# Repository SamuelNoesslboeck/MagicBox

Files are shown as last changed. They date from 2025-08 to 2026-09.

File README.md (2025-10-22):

# MagicBox

The MagicBox is a WiFi/BlueTooth- and LoRa-able, programmable radio controller for a large range of applications. 

## Hardware

<p align="center">
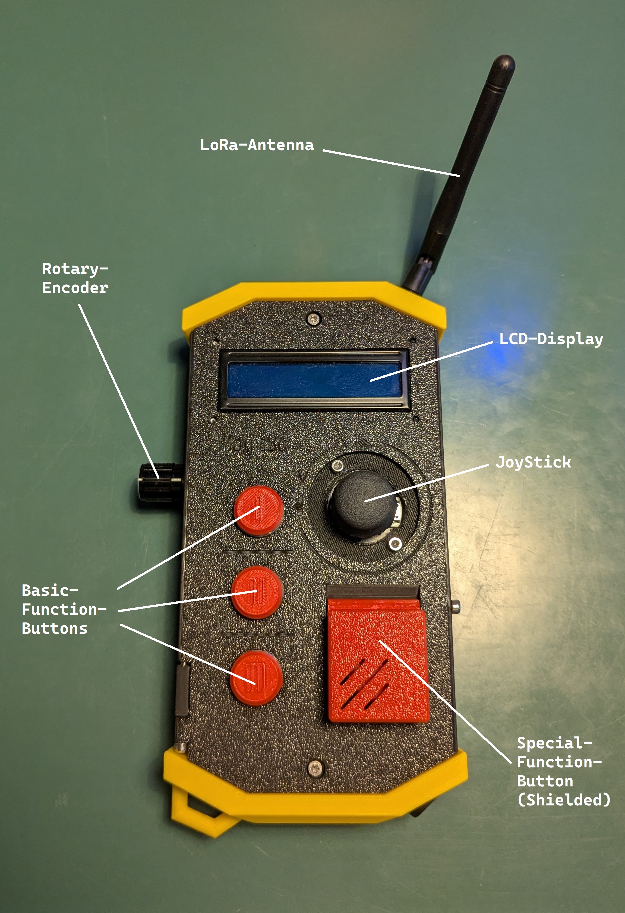
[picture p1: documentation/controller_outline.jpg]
    
</p>

Equipped with an ESP32 MCU, the controller can host quite challenging tasks and code. It's various input and output devices include:

- LCD Display
- Buzzer
- Rotary encoder
- Joystick
- 3 open and 1 shielded button

For more information, see the hardware reference [here](./documentation/hardware_reference.md).

## Software & Programming

The controller is fully programmable, meaning it can be adjusted to every application. Some basic APIs and libraries are provided:

- [magicontent](https://github.com/SamuelNoesslboeck/magicontent): Provides basic hardware bindings and APIs so you can start directly with tailoring the controller to your application
- [magicos](https://github.com/SamuelNoesslboeck/magicos): Some pre-made programs for general applications of the controller (LoRa-Mode, USB-Mode, ... )

The controller includes a simple OP-Code protocol called MBCP, which is generally transferred via LoRa. For more information, see [magicontent](https://github.com/SamuelNoesslboeck/magicontent).

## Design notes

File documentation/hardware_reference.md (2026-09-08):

# Hardware-Reference

The hardware reference gives an overview over the electrical components and connections used.

## Components used

- **MCU**: ESP32 (Type: NodeMCU32S)
- **LCD-Display**: LCD-2004 (Using a I2C adapter)
- **LoRa-Module**: 

## ESP32 - Pin reference 

| ID | Pin | Description |
|---|---|---|
| | | |
| **JoyStick** | | | 
| JS_X | 4 | Analog signal value for X direction of the Joystick (0-3.3V) |
| JS_Y | 34 | Analog signal value for Y direction of the Joystick (0-3.3V) |
| | | |
| **Buttons** | | |
| BT_A1 | 16 | First action button on the front |
| BT_A2 | 17 | Second action button on the front |
| BT_A3 | 25 | Third action button on the front |
| BT_ULT | 26 | Ultimate action button on the front |
| | | |
| **Rot-Encoder** | | |
| RE_DT | 39 | Data signal line of the rotary encoder |
| RE_CL | 36 | Clock signal line of the rotary encoder |
| RE_SW | 13 | Integrated rotary encoder button |
| | | |
| **LoRa** | | |
| LORA_SS | 5 | > |
| LORA_RST | 14 | > LoRa Data connection |
| LORA_D0 | 27 | > |
| | | |
| **Misc.** | | |
| BUZZER | 2 | PWM Pin to play notes on the buzzer |

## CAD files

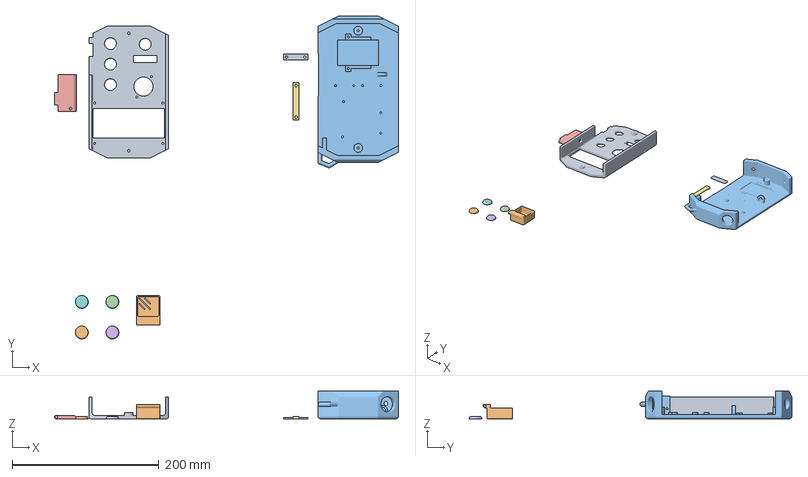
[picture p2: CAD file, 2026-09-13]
printing/a__magicbox.3mf
469.3 x 440.6 x 38.0 mm
1_top_plate.stl
3__button_cap.stl
2_outer_shell.stl
7a__button1.stl
4_left_opening.stl
7b__button2.stl
5_battery_clamp.stl
7c__button3.stl
6_module_clamp.stl
7d__buttonS.stl

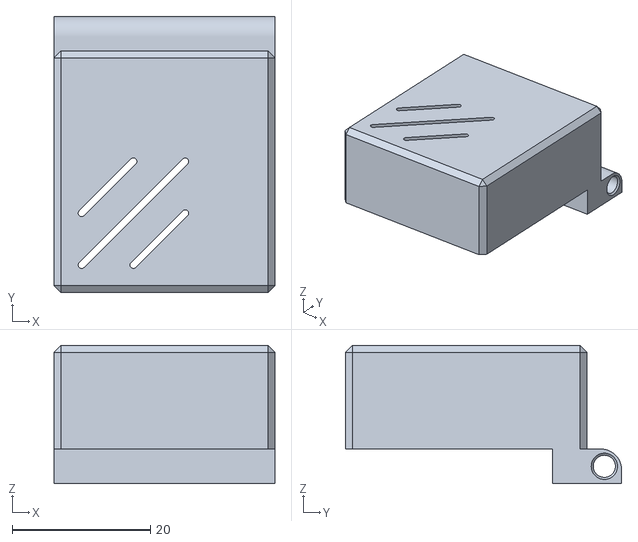
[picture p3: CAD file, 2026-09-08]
printing/3__button_cap.stl
32.0 x 40.0 x 20.0

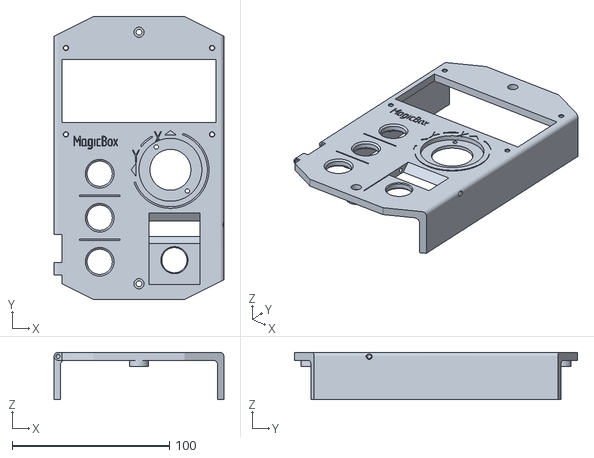
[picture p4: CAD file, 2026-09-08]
printing/1__top_plate.stl
108.0 x 180.0 x 30.0

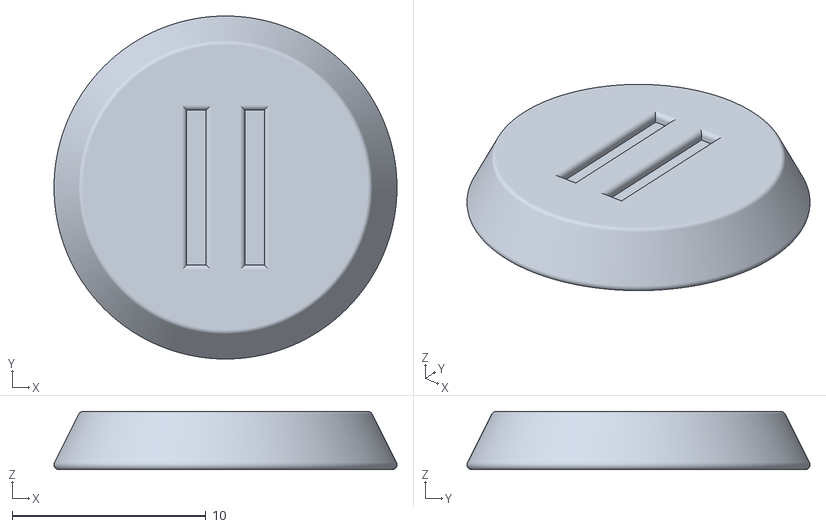
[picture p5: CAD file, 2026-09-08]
printing/7b__button2.stl
17.7 x 17.7 x 3.00

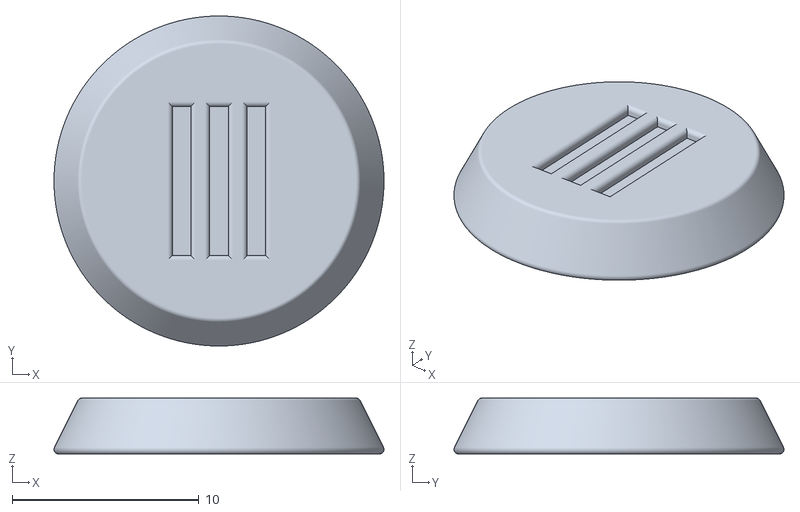
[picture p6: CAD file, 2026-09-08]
printing/7c__button3.stl
17.7 x 17.7 x 3.00

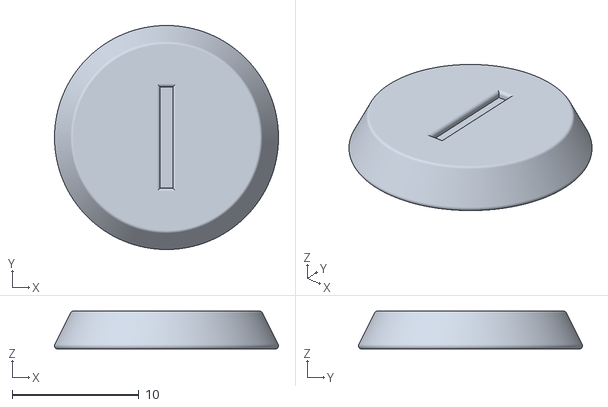
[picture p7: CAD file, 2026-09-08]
printing/7a__button1.stl
17.7 x 17.7 x 3.00

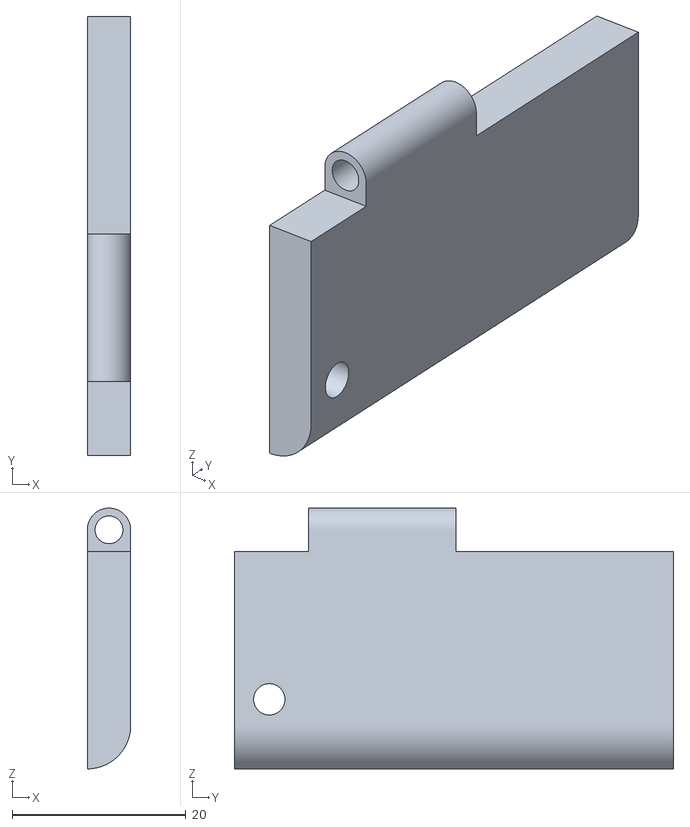
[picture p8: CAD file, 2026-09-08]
printing/4__left_opening.stl
5.00 x 50.5 x 30.0

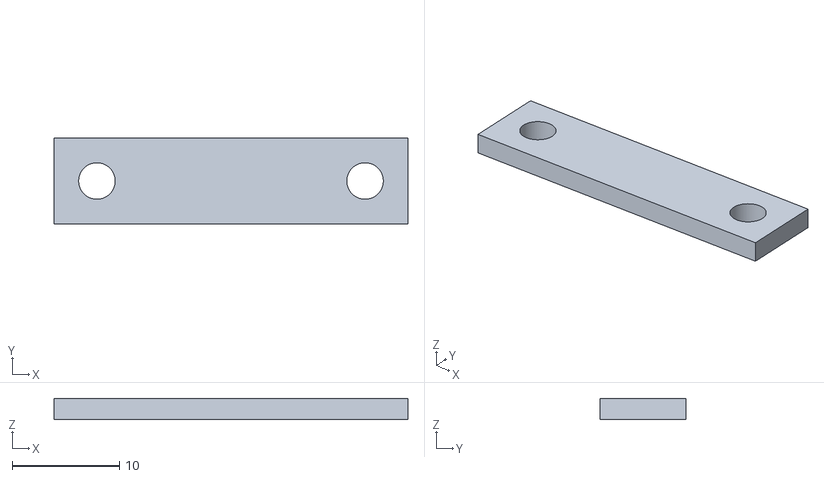
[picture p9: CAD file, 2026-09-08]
printing/6__module_clamp.stl
33.0 x 8.00 x 2.00

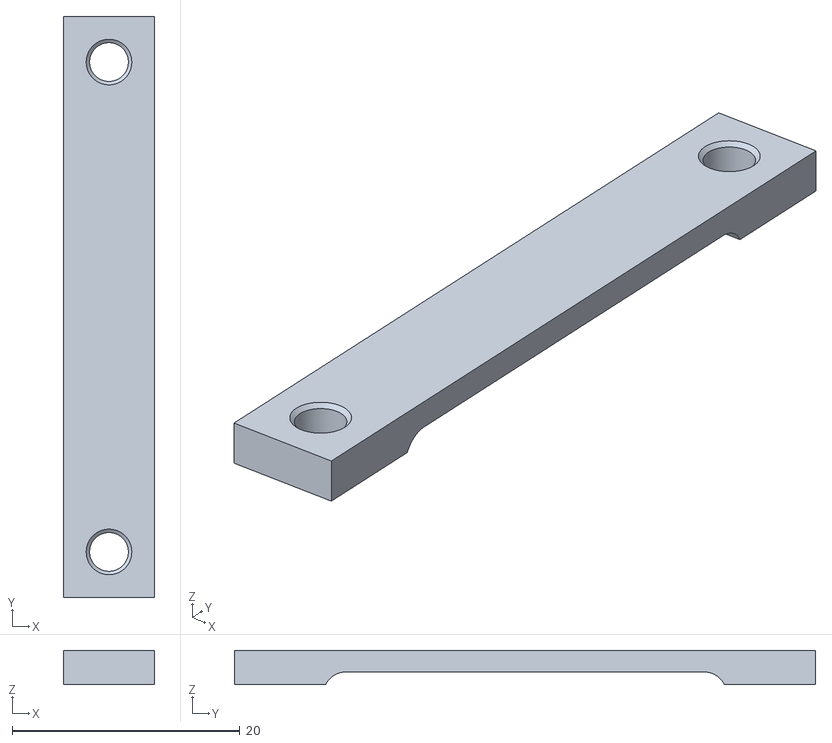
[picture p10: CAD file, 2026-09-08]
printing/5__battery_clamp.stl
8.00 x 51.0 x 3.00

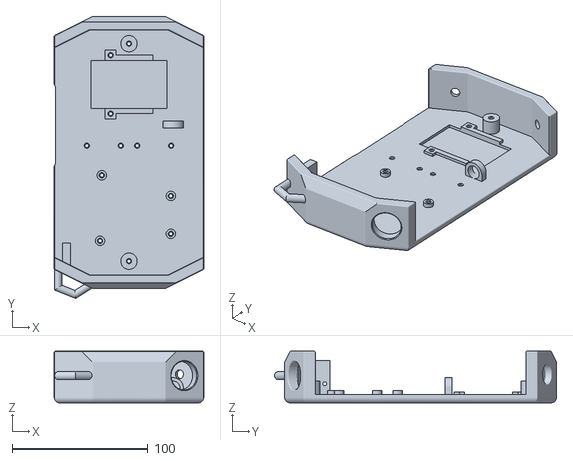
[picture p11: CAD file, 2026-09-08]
printing/2__outer_shell.stl
110.0 x 207.4 x 38.0

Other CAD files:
printing/7d__buttonS.stl
documentation/sketches/magicbox_case.blend

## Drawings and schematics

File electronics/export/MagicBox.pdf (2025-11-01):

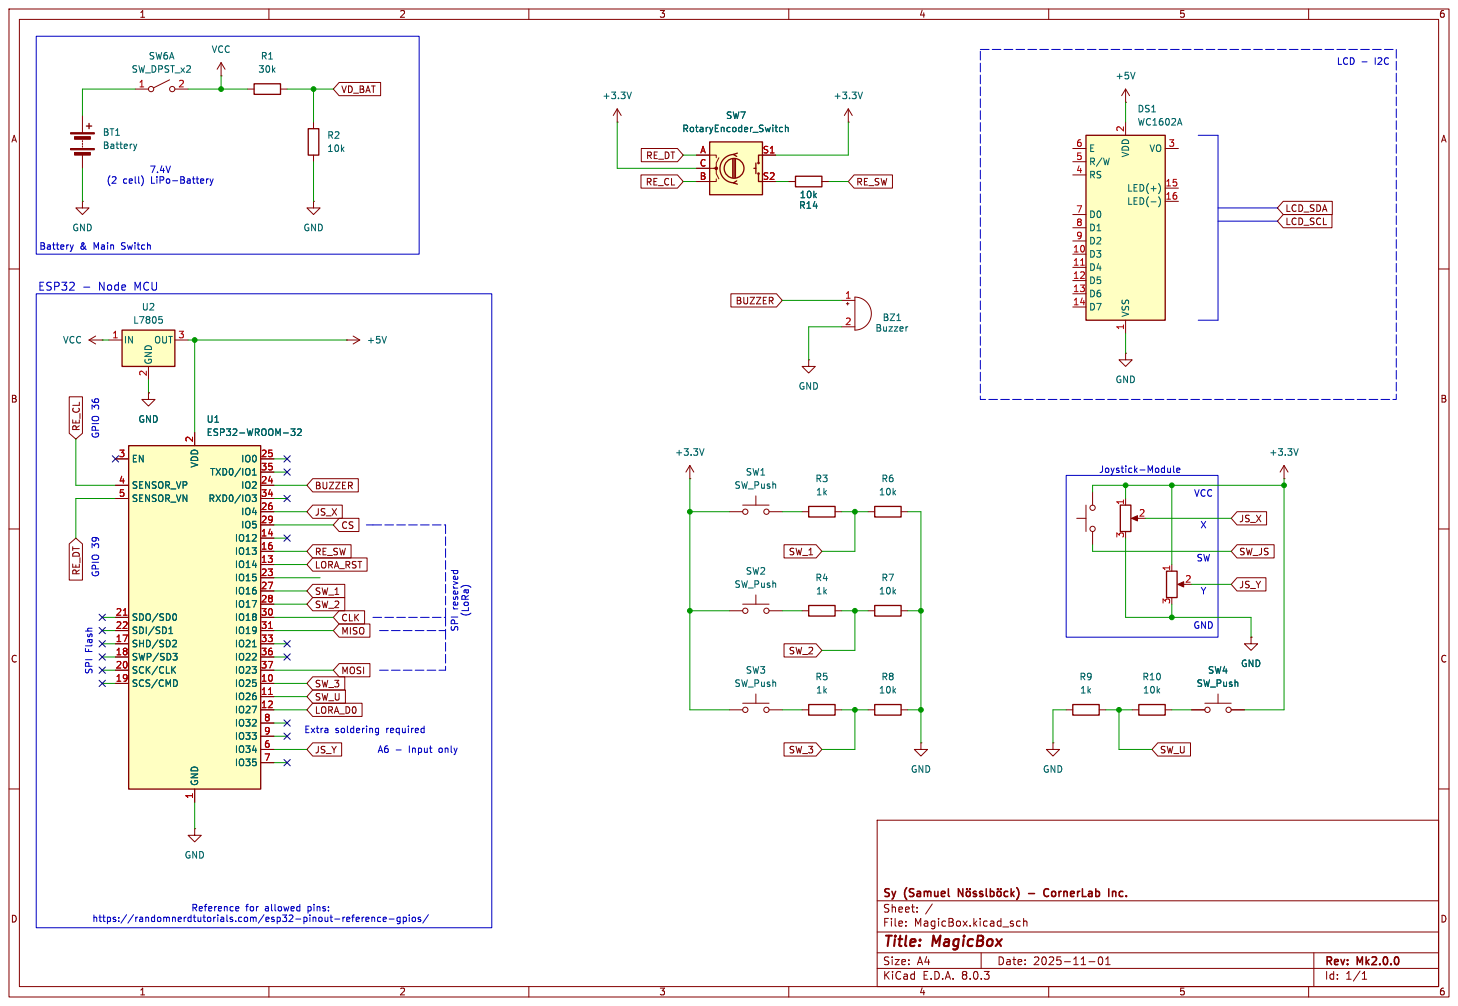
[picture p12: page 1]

2 SCK/CLK 20 SDO/SD0 21 SDI/SD1 22

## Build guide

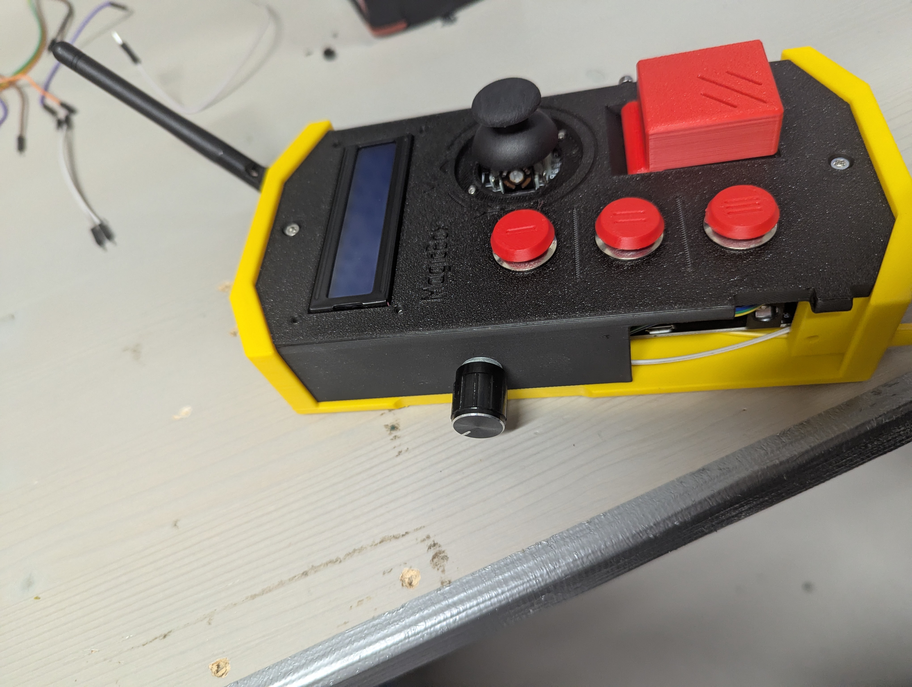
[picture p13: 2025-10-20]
documentation/pictures/6_first_build_side.jpg

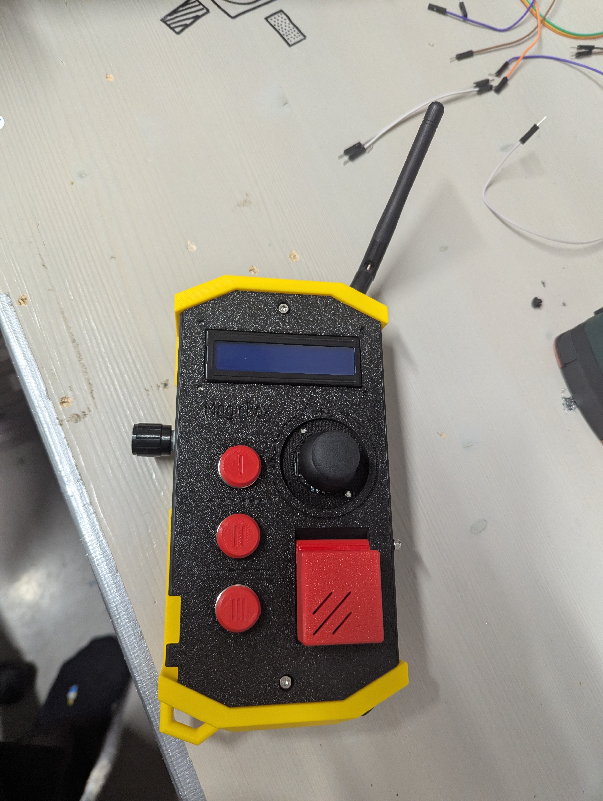
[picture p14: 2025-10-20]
documentation/pictures/5_first_build.jpg

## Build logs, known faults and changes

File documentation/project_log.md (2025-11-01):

# Project log - MagicBox

## New design Kick-Off (15/08/2025)

The controllers shape and colour scheme was inspired by controllers for cranes/robot arms and classical depictions of detonators. The focus is set on the LoRa-Connection part, as extending the Bluetooth module of the ESP32 with an antenna is not the easiest thing to do, if the ESP does not have an antenna slot built-in.

<p align="center">
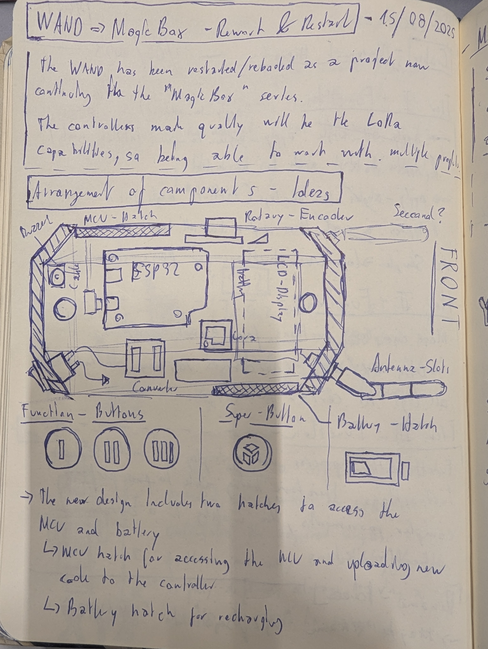
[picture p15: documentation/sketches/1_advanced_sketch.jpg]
    
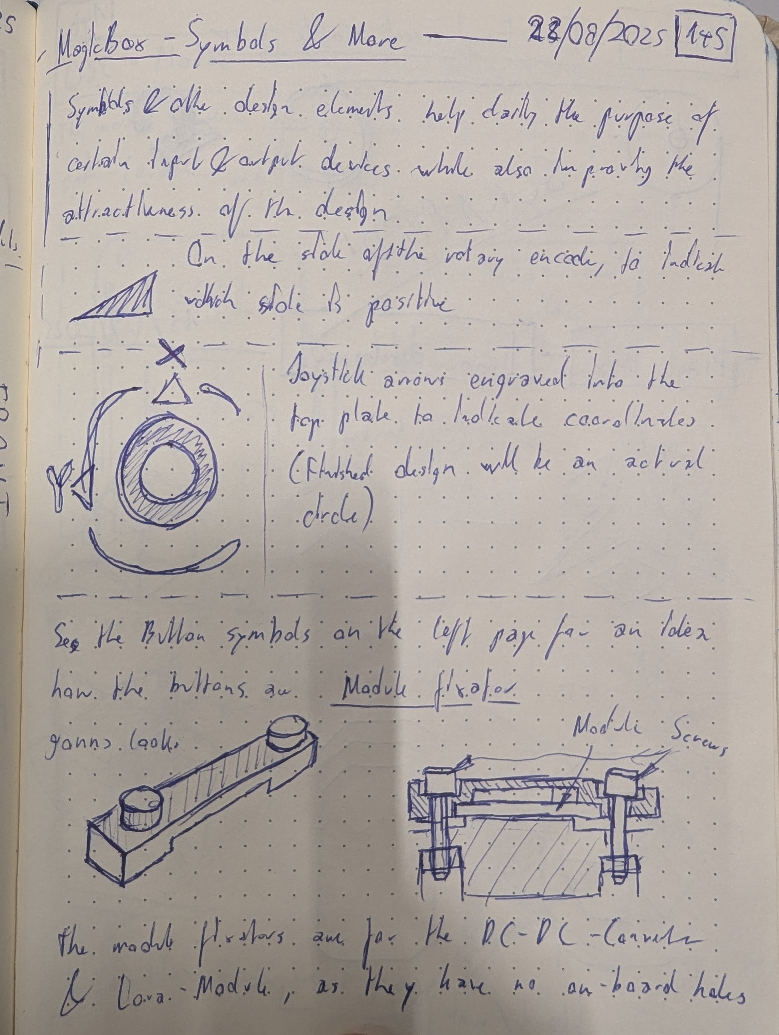
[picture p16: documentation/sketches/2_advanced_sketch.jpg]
    
</p>

## First steps to final CAD model

<p align="center">
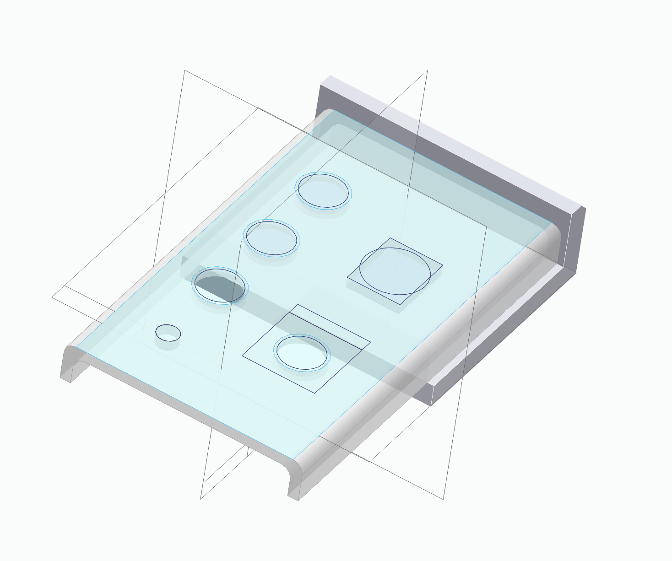
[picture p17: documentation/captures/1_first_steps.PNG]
    
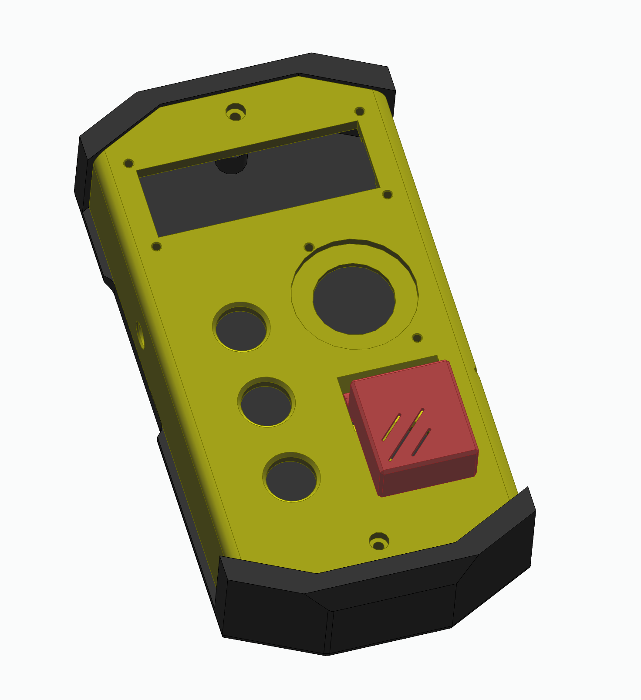
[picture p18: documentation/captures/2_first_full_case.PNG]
    
</p>

As it can be seen in the first build section, the orientation of the ESP32 has been changed later on, as it provides more space and better build-up of the other components.

## Road to first build

<p align="center">
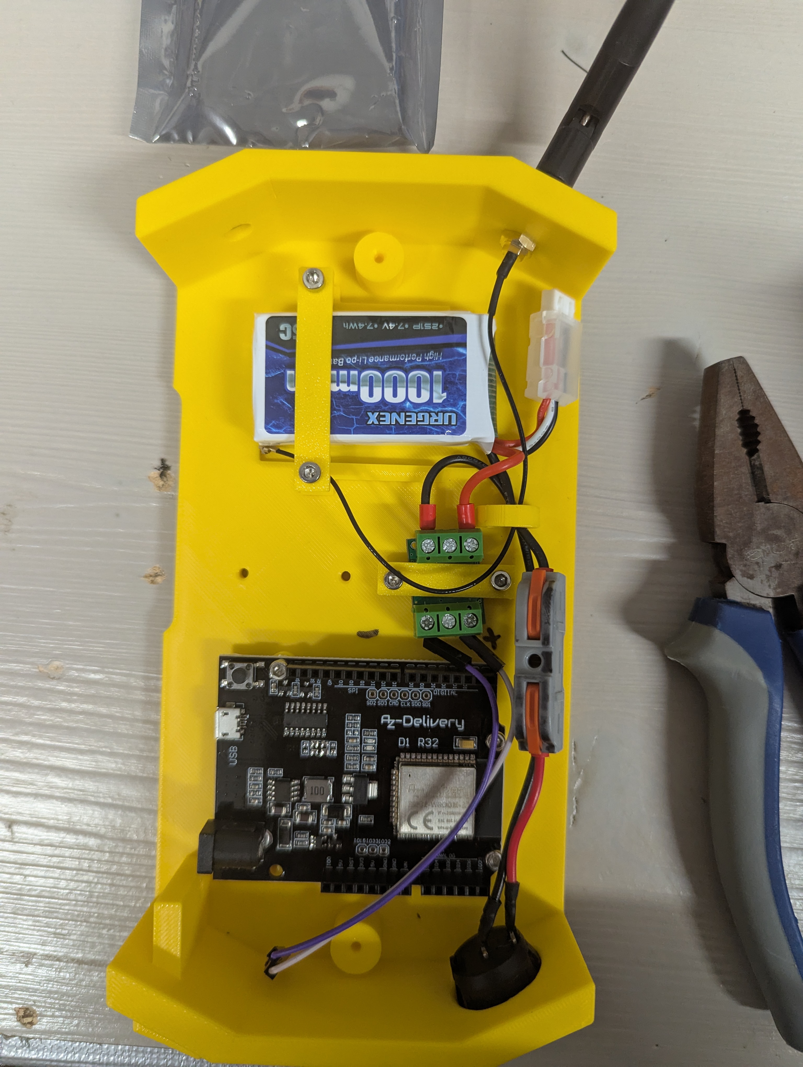
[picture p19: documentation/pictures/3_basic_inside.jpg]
    
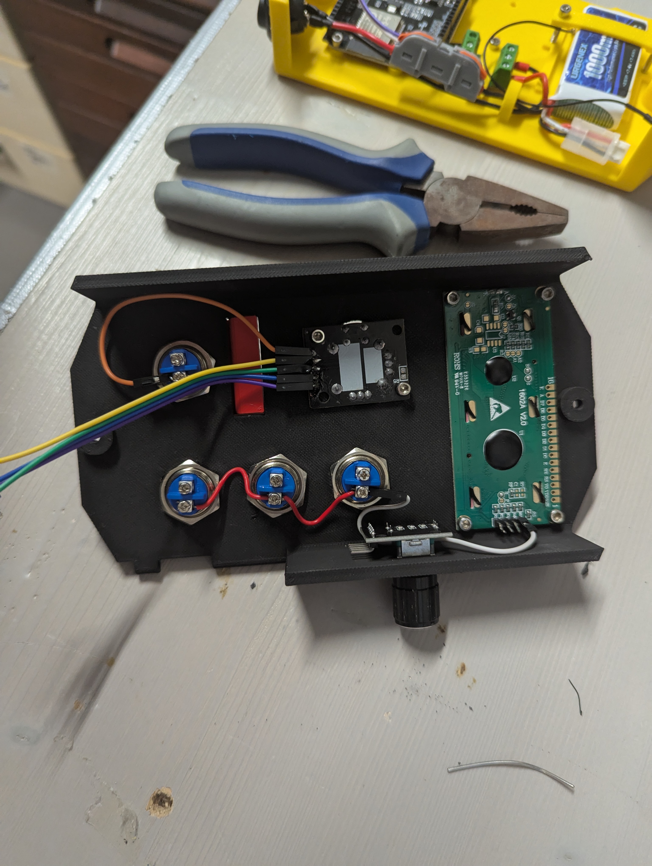
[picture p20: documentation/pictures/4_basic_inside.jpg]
    
</p>

### Unexpected behaviour issue

During the first build, to be precise during the first tests, an issue occurred where random button inputs have been triggered. The cause of this issue, after quite some tinkering, has been found to be the cause of too high voltage being supplied to the input methods. The ESP32 uses 3.3V as it's operating and input voltage, so supplying 5V to it causes undefined behaviour according to multiple sources. In this case after proper rewiring (also making sure every input mean has the right pull-down attached) the issue has been fixed too.

## Adjusting libraries and core software (20/10/2025)

The `magicontent` repo has been repurposed as a API/library repo instead of operating sketches for the controller, alongside the `sylo` library which has also been brought up to current standards.

## Finishing first release (22/10/2025)

<p align="center">
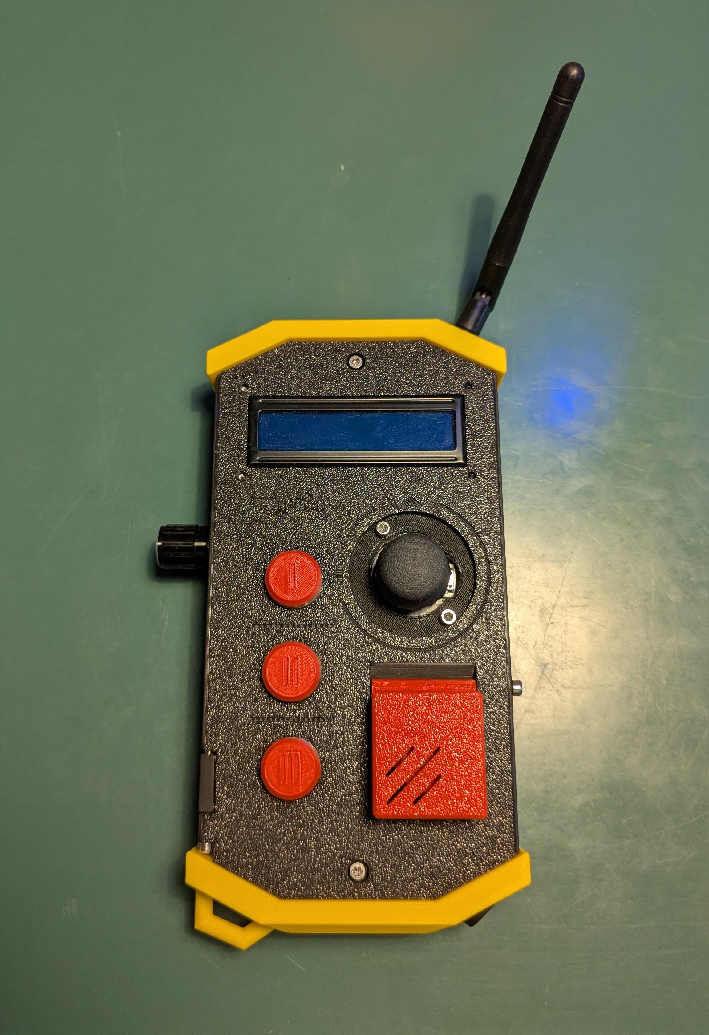
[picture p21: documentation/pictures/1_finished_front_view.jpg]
    
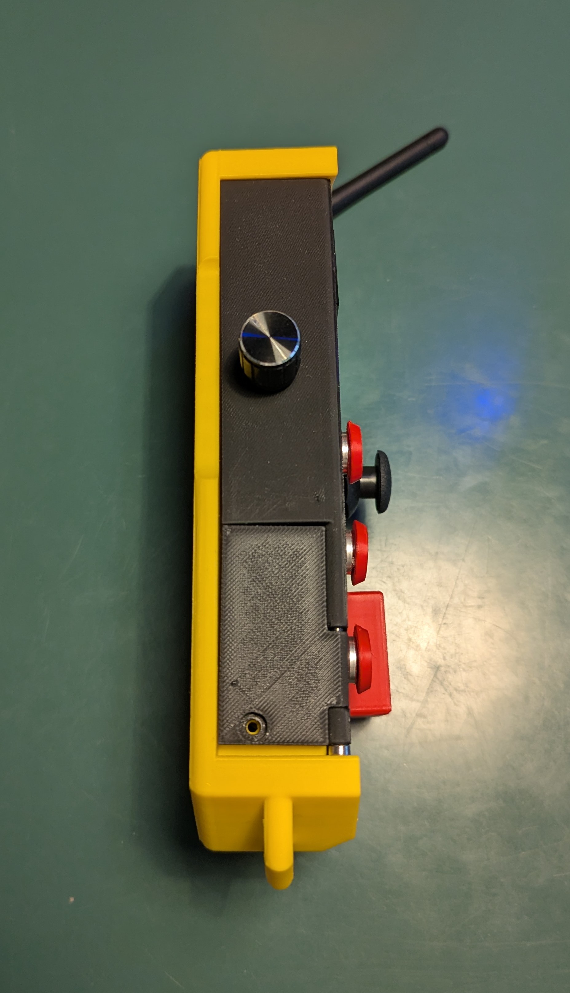
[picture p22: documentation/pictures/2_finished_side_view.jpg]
    
</p>

The release has been finished off by bringing the project log up to date, adding images of sketches and the controller itself and finishing up the hardware reference, correctly describing components used and how they are connected. Future improvements include: 

- Voltage divider added to battery in order to measure battery voltage -> Measure current battery level percent
- Include button events and other features into general `sylo` library

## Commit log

2025-08-17 starting pure hardware rework
    [1_top_plate.stl, Wand.kicad_pcb, Wand.kicad_sch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]
2025-08-17 first full shape and components tests
    [1_top_plate.stl, 3_button_cap.stl, a_magicbox.cfg]
2025-08-18 fixed typo
    [a_magicbox.cfg]
2025-08-20 adding more parts to multibody
    [a_magicbox.cfg]
2025-08-31 first outer shell tests
    [2_outer_shell.stl]
2025-09-09 case update
2025-09-11 further progress on outer shell
    [a_magicbox.cfg]
2025-09-15 finishing parts for first test build
    [1_top_plate.stl, 5_battery_clamp.stl, 6_module_clamp.stl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]
2025-09-16 first build
    [1_top_plate.stl]
2025-10-20 small opening changes
    [4_left_opening.stl]
2025-11-01 updated schematics
    [MagicBox.kicad_pcb, MagicBox.kicad_sch]
2026-01-02 Created a sketch for the MagicBox case
    [magicbox_case.blend]
2026-01-03 Created the body and cover for MagiCase
    [a_magicbox.cfg]
2026-09-08 first steps towards mk2.1 with new display
    [1__top_plate.stl, 1_top_plate.stl, 2__outer_shell.stl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]
2026-09-08 updated naming convention
    [a__magicbox.cfg, a_magicbox.cfg]
2026-09-13 small electronics and priting additions
    [MagicBox.kicad_sch, a__magicbox.3mf]
2026-09-24 starting overhawl of electronics
    [MagicBox.kicad_sch]
